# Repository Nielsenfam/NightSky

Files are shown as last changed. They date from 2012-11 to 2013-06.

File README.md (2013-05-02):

Night Sky Orb
=============

By Terry Nielsen
----------------

The Night Sky Orb is a RaspberryPi based "clock" that gives a quick summary
of the objects visible in the night sky for the current night by turning 
on/off an LED representative of each hour in the night.

Status:
-------
Working Prototype

Two versions: 
-------------

1. Tk based GUI: LEDgrid.py
2. i2c version: LEDgridDrive.py

LEDgridDrive.py needs to be run as root and should be run on startup. 

It will drive a LED matrix connected to the i2c port of the raspberry pi. 

See setup instructions, Setup.md for setting up Raspberry Pi from clean install

Notes: 
------

1. LED driver version needs more testing

Objects supported inlcude:
--------------------------

## Earth: ##
Displays an indication of the cloud cover, transparancy, and seeing
on indicates "mostly clear and at least avg transparency and avg seeing"
off indicates "not clear or poor transparancy or poor seeing"

## Sun: ##
Indicates time of sunset/sunrise "on" is sun is out.

## Moon: ##
Indicates when the moon is visible, "on" is moon is out, brightness 
indicates how bright the moon is.

## ISS: ##
Any International Space Station Passes, count the # of flashes 
to tell what the 10 minute period of the hour it is visible.

## Venus: ##
On indicates Venus is visible that hour 

## Mars: ##
On indicates Mars is visible that hour

## Saturn: ##
On indicates Saturn is visible that hour

## Jupiter: ##
On indicates Jupiter is visible that hour

Originally designed for an 8x8 LED matrix to go from hours 7PM to 2AM and 
driven directly by an Arduino with a wifi connection to the code on a 
seperate server.

Redesigned for RaspberryPi, with local code connected to a wifi dongle 
and an LED matrix driven by i2c bus driver.

Enhancement Ideas:
=================

1. The i2c LED matrix could be larger to cover 12 hours for the whole "night". 
Might be easier to use a second Backpack at a different address

2. The Earth Sky conditions could display additional observing conditions 
such as those found on cleardarksky.com.

3. i2c could also drive additional 7 segement display for 
traditional "clock" functionality.

4. Combined with Above, a pushbutton could be used to display exact 
times of Rise/Set on a 7 segment display

5. Another button could also display details of sky conditions

6. Make configurable which night sky objects to show

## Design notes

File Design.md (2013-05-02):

Project: Easy to View Night Sky Summary Display "Clock"
=======================================================

Name: NightSkyOrb
-----------------

Queries server each day to get status of sun rise/set, moon rise/set, planets visible, weather summary, and ISS passes.

Do as a "grid" of 8 x 8 LEDs:

- For each body show visible Time Of Day: 7,8,9,10,11,12,1,2

- Off = not visible, dim = rising/setting, bright = in sky
	
1. Earth (Sky): Earth: Off = Cloudy, Dim = Party Cloudy, Bright = Clear Skys
2. Sun: Sun: On = visible, Off = not visible (or should this reverse?)
3. Moon: Moon: Off = not visible, dim = 0-20 degrees, dim = above 20 degrees but less than half full, bright = above 20 degrees, more than half full
4. ISS: Off = not visible, Visible Pass, flashes 1 time for every 10 minutes past hour
5. Venus: Bright = In Sky, above 10 degrees, Dim = 0-20 degrees, Off = not visible
6. Mars: Bright = In Sky, above 10 degrees, Dim = 0-20 degrees, Off = not visible
7. Jupiter: Bright = In Sky, above 20 degrees, Dim = 0-20 degrees, Off = not visible
8. Saturn: Bright = In Sky, above 20 degrees, Dim = 0-20 degrees, Off = not visible

Message String:
----------------
Originally designed to communicate to Arduino, not really needed now

header: 'X', 
row num=0-9, 
col count=8, 
ascii data string one char per column, footer: 'Z\n',  

info for each LED: 
	
+ a = off
+ b = dim
+ c = on/bright
+ d = slow flash 10 secs on, 10 off	
+ f = slow flash 10 seconds on 10 off
+ g = 1 flash: 1 sec on, 1 off, 10 off (for minutes :00-09:59)
+ h = 2 flash: 1 on, 1 off, 1 on, 1 off, 10 sec off (for minutes :10-19:59)
+ i = 3 flash: 1 on, 1 off, 1 on, 1 off, 1 on, 1 off, 10 off (for minutes :20-29:59)
+ j = 4 flash: 4x 1 on/off, 10 off (for minutes :30-39:59)
+ k = 5 flash: 5x 1 on/off, 10 off (for minutes :40-49:59)
+ l = 6 flash: 6x 1 on/off, 10 off (for minutes :50-59:59)

Example: row 2 is for sun setting in 9PM hour:
		X28ccbaaaaaZ\n
		
Example: row 3 is for near full moon rising at 10PM:
		X38aaabccccZ\n
		
Example: row 4 is for ISS making a visible pass at 10:35PM
		X48aaajaaaaZ\n
		
Example: row 6 is for Mars visible from sunset (9PM) till 11PM, going to 20 degrees from horizon in 10PM hour
		X46aabcbaaaZ\n 	

LED display:
------------

Now using Adafruit LED backpack
 		
Intend to put individual LEDs into a frame similar to:

http://www.flickr.com/photos/spikenzie/3674197080/in/set-72157603968192071/	
 		
from: http://www.spikenzielabs.com/SpikenzieLabs/Main.html
http://www.spikenzielabs.com/SpikenzieLabs/8x8.html	

with LEDS could color code by object:
+ Sun: Yellow
+ Earth: Blue
+ Moon: White
+ ISS: Blue
+ Venus: Yellow
+ Mars: Red
+ Jupiter: Orange
+ Saturn: Yellow
	
A row of LEDS for each object, and then a label on the top or side of the object for hours?
	
Time is on the X axis. 

Use IKEA picture frame

LEDs in http://www.spikenzielabs.com/SpikenzieLabs/8x8.html

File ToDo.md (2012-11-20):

To Do:
======

GUI:
----

+ clean up code
	
+ comment code
	
+ build test stubs

+ better error handling
	
+ parameterize location (both cleardarksky and lat/lon/alt)
+ parameterize start and end times (7PM-2PM currently hardcoded)
+ parameterize colors (for GUI)
+ parameterize objects, other planets, satallites, 

LEDdriver:
----------

+ make work with 2 LED arrays for more hours

Next Steps:
-----------

+ Design Frame
+ Build Frame
+ Mount LEDs
+ Wire LED array
+ Build and Test

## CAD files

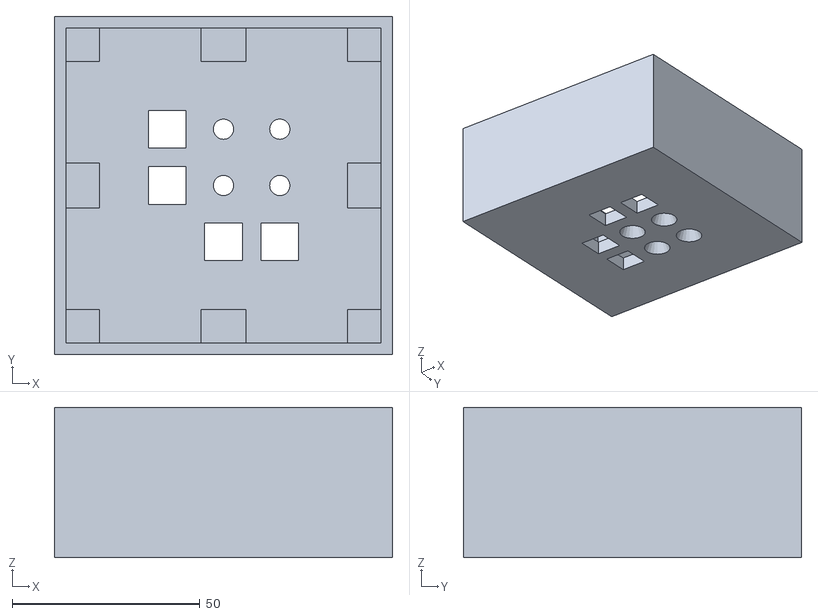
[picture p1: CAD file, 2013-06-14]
case/MainBox-test.stl
90.0 x 90.0 x 40.0

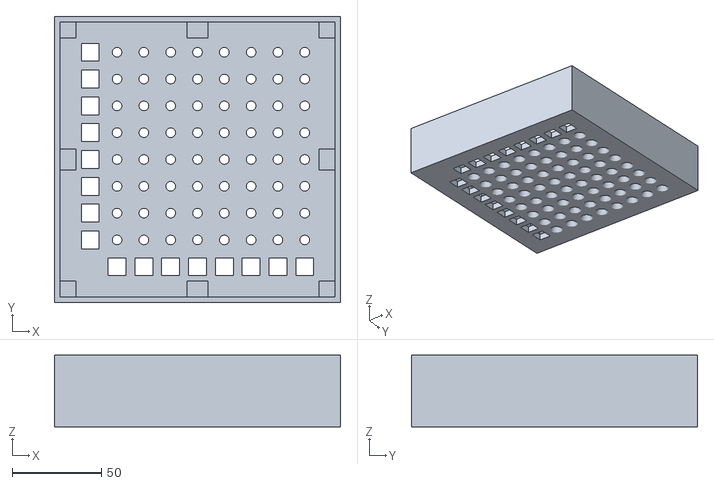
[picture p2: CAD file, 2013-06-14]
case/MainBox.stl
160.0 x 160.0 x 40.0

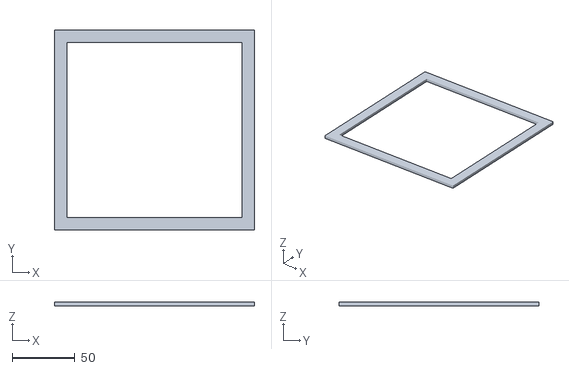
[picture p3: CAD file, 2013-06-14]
case/DecorFrame.stl
160.0 x 160.0 x 3.00

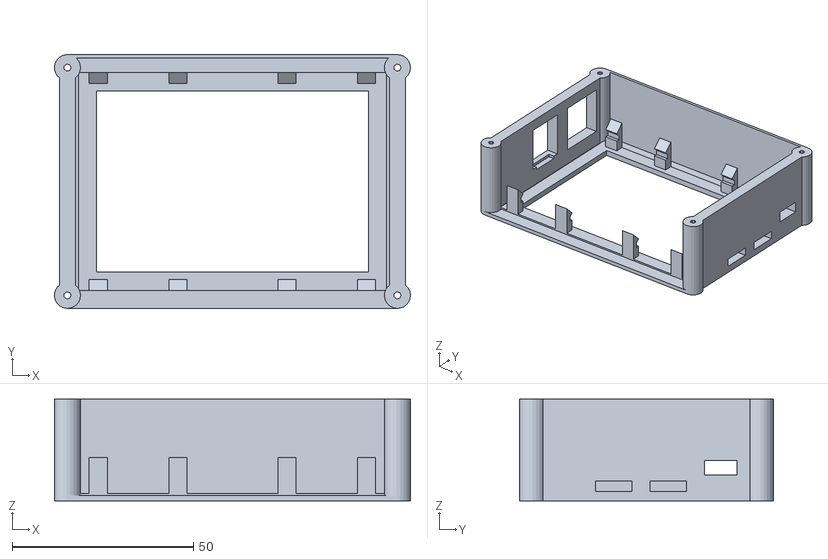
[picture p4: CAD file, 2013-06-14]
case2/base.stl
98.2 x 70.0 x 28.0

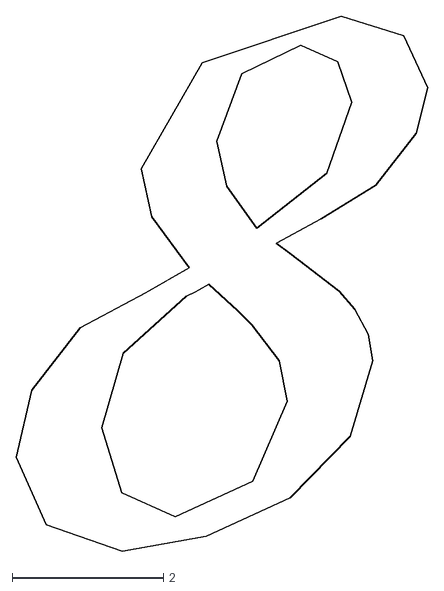
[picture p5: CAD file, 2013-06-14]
case/eight.dxf
5.44 x 7.07

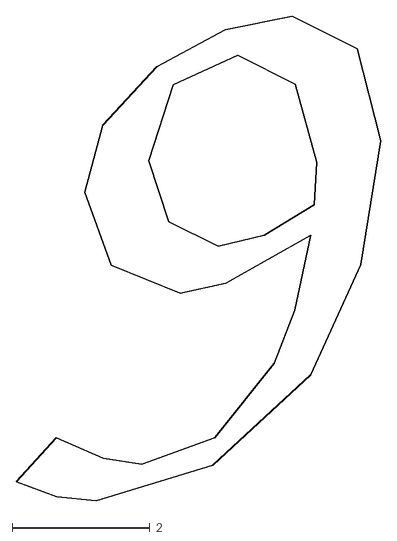
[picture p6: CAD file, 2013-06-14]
case/nine.dxf
5.30 x 7.05

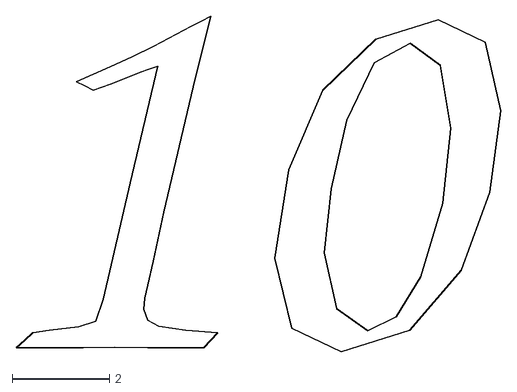
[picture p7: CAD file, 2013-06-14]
case/ten.dxf
9.96 x 6.90

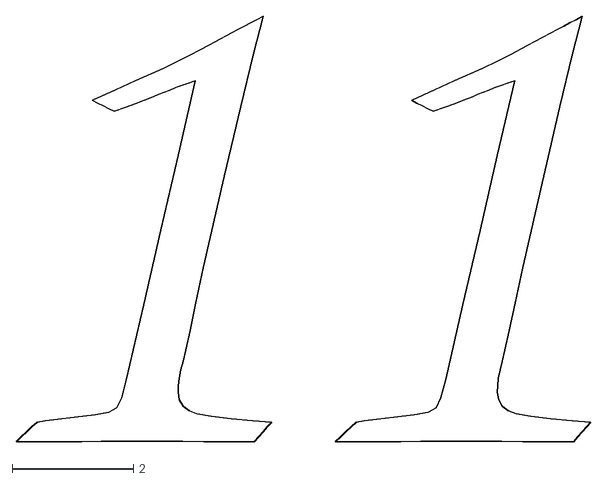
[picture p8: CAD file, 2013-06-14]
case/eleven.dxf
9.49 x 7.02

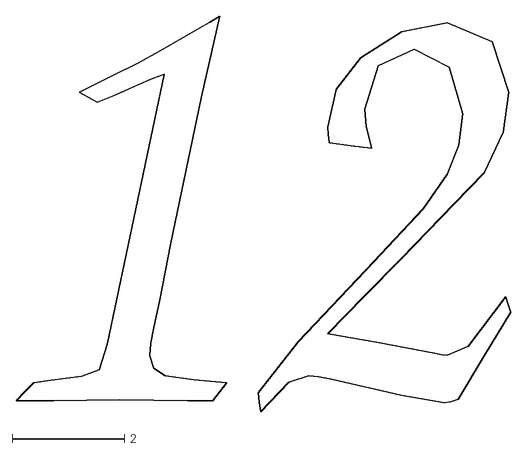
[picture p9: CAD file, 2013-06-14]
case/twelve.dxf
8.83 x 7.06

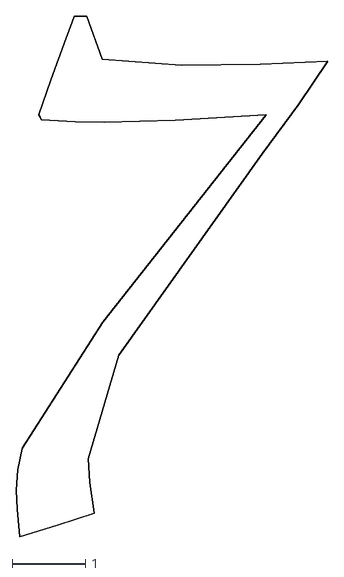
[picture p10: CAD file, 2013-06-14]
case/seven.dxf
4.24 x 7.10

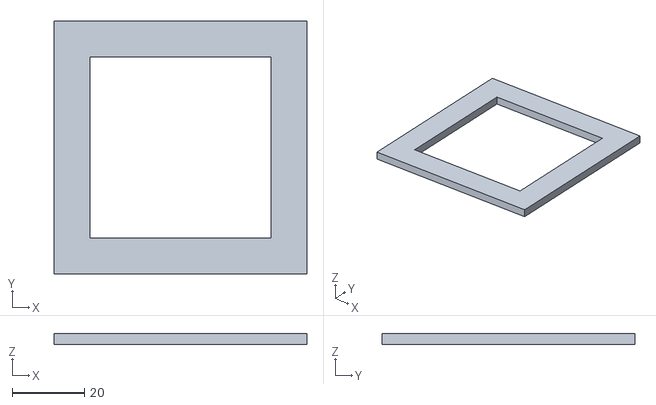
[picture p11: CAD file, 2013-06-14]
case/DecorFrame-test.stl
70.0 x 70.0 x 3.00

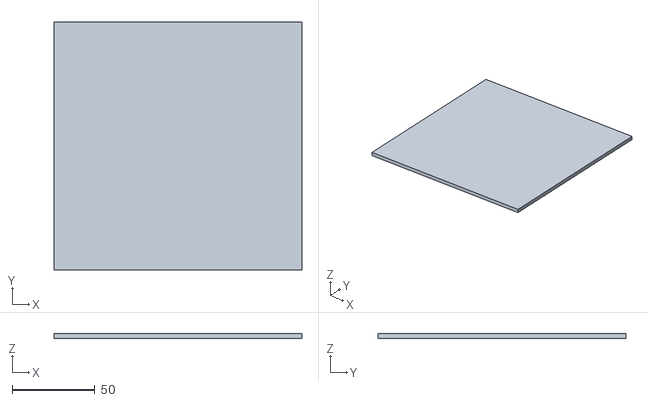
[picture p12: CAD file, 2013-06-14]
case/BackPanel.stl
149.5 x 149.5 x 3.00

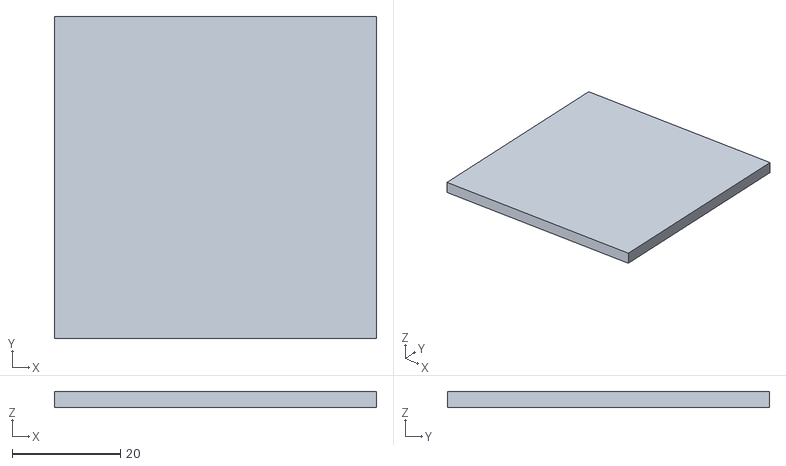
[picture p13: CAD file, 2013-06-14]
case/BackPanel-test.stl
59.5 x 59.5 x 3.00

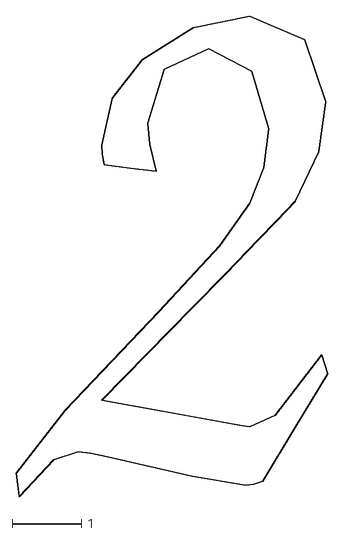
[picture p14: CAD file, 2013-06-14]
case/two.dxf
4.51 x 6.95

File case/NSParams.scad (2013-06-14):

//
// box for Night Sky Orb LED clock
//   designed by: Terry Nielsen
//
//   Parameter File
//

//
// box parameters
//

// Square box of this size in mm

// test: box_width = 90;
box_width = 160;

// box is this deep in mm

box_depth = 40;

// box has walls this thick in mm
wall_thickness=3;

// box has corner braces this size in mm
corner_size = 12;

// make lip on decorative frame of front of panel
lip_width = 10;
lip_thickness = 3;

// front panel is this thick in mm
panel_thickness=5;

// back panel is this thick in mm
back_panel_thickness = 3;

// corner braces are recessed from the back
corner_recess=back_panel_thickness + 2;

// size of object holes
object_hole_size = 10;

// seperation between object holes and grid holes
object_grid_seperation = 5;


//
// LED parameters
//

// number of LEDs in row:

// test: led_row_count = 2;
led_row_count = 8;
led_col_count = led_row_count; // make it a square grid

// LED hole resolution

led_resolution = 20;

// LED holes have this diamter in mm
led_hole_back_dia=5;

// make this bigger to make hole wider at front of panel
led_hole_front_dia=led_hole_back_dia*2;

// LED holes are spaced this far apart in the grid in mm
led_hole_spacing=15;

// LED grid hole pattern is offset from the sides this far:
led_hole_pattern_offset = 
    ( ( box_width
        - ( led_hole_spacing*(led_row_count-1) ) ) / 2 )
    + ( ( object_hole_size + object_grid_seperation ) / 2 );

//
// End of parameters
//

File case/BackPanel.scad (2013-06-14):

//
// box for Night Sky Orb LED clock
//   designed by: Terry Nielsen
//

include <NSParams.scad>

//
// draw back panel
//

cube(size=[(box_width-wall_thickness*2)-0.5,
           (box_width-wall_thickness*2)-0.5,
           back_panel_thickness]);

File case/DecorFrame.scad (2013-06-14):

//
// box for Night Sky Orb LED clock
//   designed by: Terry Nielsen
//

include <NSParams.scad>

// A simple decorative frame to go on front panel

// draw box lip
difference() {
   cube(size=[box_width,box_width,lip_thickness]);
   translate([lip_width,lip_width,0])
      cube(size=[box_width-lip_width*2,
                 box_width-lip_width*2,
                 lip_thickness]);
}

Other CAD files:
case/one.dxf
case/MainBox.scad
case2/base.scad
case2/ledmatrix.scad
case2/pibase.scad

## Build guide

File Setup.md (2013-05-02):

Instructions to setup a Raspberry Pi to run the NightSkyOrb
===========================================================

Set up new SD card with raspbian distribution
---------------------------------------------

Insert SD card and do config:
     Expand to full card, reset password, set timezone

setup wifi
----------

Using gui tool on desktop

setup keyboard
--------------

    # sudo vi /etc/default/keyboard and change "gb" to "us"

reboot after that

    # sudo reboot

get current updates
-------------------

In terminal window do this to get to most current packages:

    # sudo apt-get update
    # sudo apt-get upgrade

setup python development environment
------------------------------------

In terminal window get python development environment and python install package tool

    # sudo apt-get install python-pip python-dev

setup necessary python packages for astronomical calculations
-------------------------------------------------------------

get stuff for calculating ephem by getting pyephem and putz packages:

    # sudo pip install pyephem pytz

setup git so we can retrieve code
---------------------------------

get git so we can get NightSky code:

    # sudo apt-get install git

retrieve code from github:

    # git clone http://github.com/Nielsenfam/NightSky

Setup for GPIO and i2c access from python
-----------------------------------------

    # sudo apt-get install python-rpi.gpio
    # sudo apt-get install python-smbus i2c-tools

Now enable gpio and smbus access from kernel:

    # sudo vi /etc/modules

in editor add these two lines to end of file:

    i2c-bcm2708 
    i2c-dev

And also need to remove from blacklist

    # sudo vi /etc/modprobe.d/raspi-blacklist.conf

in vi comment out two lines:

    blacklist spi-bcm2708
    blacklist i2c-bcm2708

And finally need to reboot to get kernel updated

    # reboot

Configuring and Validation
--------------------------

Edit params.py to match location:

    # vi params.py

Change latitude, longitude, and cleardarksky location

To validate it all works:

    # sudo python LEDgrid.py

if all is working should see desktop graphical "LED" version of the NightSkyOrb

Now test the LED matrix grid version: 

RiPi needs to have LED 8x8 grid backpack connected to GPIO, see instructions from Adafruit

    # sudo i2cdetect -y 0

Change to 1 if on 512Mb

should see 70 if backpack is connected

Now test LED grid by typing this:

    # sudo test_LEDmatrix.py

LED matrix should scan all elements

Now run the LEDgridDrive.py version:

    # sudo python LEDgridDrive.py

If it all works, the LEDs should look same as the desktop graphical LED orb

Setup Desktop Icon
------------------

    # cp nightsky.desktop ~/Desktop

Setup to autostart
------------------

    # sudo vi /etc/rc.local

add this to file right before the Print My IP address comment

    /home/pi/NightSky/nightsky.sh start

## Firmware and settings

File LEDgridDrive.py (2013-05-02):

#!/usr/bin/python

import os
import time
import datetime

from Adafruit_8x8 import EightByEight

import NSEphem

try:
   grid = EightByEight(address=0x70)
except IOError:
   print "LED Grid not connected, exiting"
   exit()

def flash(r,c,cnt,t):
   if ( cnt*2 > t ):
      if (t % 2 == 0 ):
        grid.setPixel(r,7-c,1)
      else:
        grid.setPixel(r,7-c,0)
   else:
      grid.setPixel(r,7-c,0)

ticks = 0
day_done = -1

while (True): 

   # refresh strings every day at 8AM
   now = datetime.datetime.now()
   if ( day_done != now.day ):
      # print "day, hour, minute", now.day, now.hour, now.minute

      if ((now.hour == 8 and now.minute < 5) or (day_done == -1)):
         # print "getting new strings"
         All_NS_obj = NSEphem.CreateAllNightSkyStrings()
         all_NS_strings = All_NS_obj.get_all_NS_strings()
         day_done = now.day

   ticks = ticks +1
   if (ticks > 20): 
      ticks = 0
            
   for row, aNightSkyString in enumerate(all_NS_strings):      
           
      NS_object_string = aNightSkyString
            
      # test strings:

      #   Earth
      #if (row == 1):
      #   NS_object_string = "X18ccccccccZ"

      #   Sun
      #if (row == 2):
      #   NS_object_string = "X28ccaaaaaaZ"

      #   Moon
      #if (row == 3):
      #   NS_object_string = "X38cbaaaaaaZ"

      #   ISS
      #if (row == 4):
      #   NS_object_string = "X48aaajakaaa"

      #   Venus
      #if (row == 5):
      #   NS_object_string = "X58cccaaaaaZ"

      #   Mars
      #if (row == 6):
      #   NS_object_string = "X68abccccccZ"

      #   Jupiter
      #if (row == 7):
      #   NS_object_string = "X78aaaaaaabc"

      #   Saturn
      #if (row == 8):
      #   NS_object_string = "X88ccbaaaaaa"

      #print "row, string", row, NS_object_string
            
      for col in range (0,8):
         char = NS_object_string[col+3]
         if (char=='a'):
             grid.setPixel(row,7-col,0)
         if (char=='b'):
             grid.setPixel(row,7-col,1)
         if (char=='c'):
             grid.setPixel(row,7-col,1)
         if (char=='g'):
             flash(row,col,1,ticks)
         if (char=='h'):
             flash(row,col,2,ticks)
         if (char=='i'):
             flash(row,col,3,ticks)
         if (char=='j'):
             flash(row,col,4,ticks)
         if (char=='k'):
             flash(row,col,5,ticks)
         if (char=='l'):
             flash(row,col,6,ticks)

   time.sleep(0.1)

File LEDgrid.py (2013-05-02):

#!/usr/bin/python

import os
import sys


from Tkinter import *
from functools import partial

import NSEphem

class LEDGrid:
    
    def __init__(self, top):

        file = sys.argv[0]
        __dir__ = os.path.dirname(file)
        # __dir__ = os.path.dirname(os.path.abspath(__file__))
        self.LED_red_on_photo = PhotoImage(file=os.path.join(__dir__,'LED-red-on.gif'))
        self.LED_yellow_on_photo = PhotoImage(file=os.path.join(__dir__,'LED-yellow-on.gif'))
        self.LED_blue_on_photo = PhotoImage(file=os.path.join(__dir__,'LED-blue-on.gif'))
        self.LED_orange_on_photo = PhotoImage(file=os.path.join(__dir__,'LED-orange-on.gif'))
        self.LED_white_on_photo = PhotoImage(file=os.path.join(__dir__,'LED-white-on.gif'))
        self.LED_red_dim_photo = PhotoImage(file=os.path.join(__dir__,'LED-red-dim.gif'))
        self.LED_yellow_dim_photo = PhotoImage(file=os.path.join(__dir__,'LED-yellow-dim.gif'))
        self.LED_blue_dim_photo = PhotoImage(file=os.path.join(__dir__,'LED-blue-dim.gif'))
        self.LED_orange_dim_photo = PhotoImage(file=os.path.join(__dir__,'LED-orange-dim.gif'))
        self.LED_white_dim_photo = PhotoImage(file=os.path.join(__dir__,'LED-white-dim.gif'))
        self.LED_off_photo = PhotoImage(file=os.path.join(__dir__,'LED-off.gif'))
        self.Earth_photo = PhotoImage(file=os.path.join(__dir__,'earth.gif'))
        self.Sun_photo = PhotoImage(file=os.path.join(__dir__,'sun.gif'))
        self.Moon_photo = PhotoImage(file=os.path.join(__dir__,'moon.gif'))
        self.ISS_photo = PhotoImage(file=os.path.join(__dir__,'ISS.gif'))
        self.Venus_photo = PhotoImage(file=os.path.join(__dir__,'venus.gif'))
        self.Mars_photo = PhotoImage(file=os.path.join(__dir__,'mars.gif'))
        self.Jupiter_photo = PhotoImage(file=os.path.join(__dir__,'jupiter.gif'))
        self.Saturn_photo = PhotoImage(file=os.path.join(__dir__,'saturn.gif'))
        self.Seven_photo = PhotoImage(file=os.path.join(__dir__,'Seven.gif'))
        self.Eight_photo = PhotoImage(file=os.path.join(__dir__,'Eight.gif'))
        self.Nine_photo = PhotoImage(file=os.path.join(__dir__,'Nine.gif'))
        self.Ten_photo = PhotoImage(file=os.path.join(__dir__,'Ten.gif'))
        self.Eleven_photo = PhotoImage(file=os.path.join(__dir__,'Eleven.gif'))
        self.Twelve_photo = PhotoImage(file=os.path.join(__dir__,'Twelve.gif'))
        self.One_photo = PhotoImage(file=os.path.join(__dir__,'One.gif'))
        self.Two_photo = PhotoImage(file=os.path.join(__dir__,'Two.gif'))
        self.H_Wood_photo = PhotoImage(file=os.path.join(__dir__,'H-Wood.gif'))
        self.V_Wood_photo = PhotoImage(file=os.path.join(__dir__,'V-Wood.gif'))
        self.bg_color = "#D2691E"
        self.border_color = "#000000"
        self.ticks = 0
        
        self.top = top
        self.button_dic = {}     ## pointer to buttons and StringVar()
        self.button_state_dic = {"on":[], "off":[], "dim":[], "flash1":[], "flash2":[], "flash3":[], "flash4":[], "flash5":[], "flash6":[]}

        self.top.title('Night Sky Orb')
        self.top_frame = Frame(self.top, width =700, height=700, bg=self.bg_color)
        self.buttons()
        self.top_frame.grid(row=0, column=1)
        
        self.create_left_labels()
        
        self.All_NS_obj = NSEphem.CreateAllNightSkyStrings()

        #exit = Button(self.top_frame, text='Exit', \
        #     command=self.top.quit).grid(row=10,column=0, columnspan=5)
        
        #update = Button(self.top_frame, text='Update', \
        #     command=self.update_cb_handler).grid(row=10,column=2, columnspan=5)

        all_NS_strings = self.All_NS_obj.get_all_NS_strings()

        for i, aNightSkyString in enumerate(all_NS_strings):      
            
            NS_object_string = aNightSkyString
            row = i + 1
            
            # test code for flashing test
            #if row == 4:
            #    NS_object_string = "X48lgahaijkZ"
            
            
            #print "row, string", row, NS_object_string
            #print NS_object_string
            

            
            self.update_LED_row(row, NS_object_string)
                            
        #print "creating bottom labels"    
        self.create_bottom_labels(10)
        
        self.blink()        
        
    def create_left_labels(self):
        for j in range(0,11):
            ColLbl = Label(self.top_frame,image=self.V_Wood_photo,height=54,width=54,relief="flat",fg=self.border_color,bd=0)
            ColLbl.grid(row=j, column=0)
                  
    def create_top_labels(self):
        for j in range(1,10):
            ColLbl = Label(self.top_frame,image=self.H_Wood_photo,height=54,width=66,relief="flat",bd=0)
            ColLbl.grid(row=0, column=j)
        ColLbl = Label(self.top_frame, bg=self.bg_color)
        ColLbl.grid(row=1, column=1)
        ColLbl = Label(self.top_frame, image=self.Seven_photo, bg=self.bg_color,height=50,width=50)
        ColLbl.grid(row=1, column=2)
        ColLbl = Label(self.top_frame, image=self.Eight_photo, bg=self.bg_color,height=50,width=50)
        ColLbl.grid(row=1, column=3)
        ColLbl = Label(self.top_frame, image=self.Nine_photo, bg=self.bg_color,height=50,width=50)
        ColLbl.grid(row=1, column=4)
        ColLbl = Label(self.top_frame, image=self.Ten_photo, bg=self.bg_color,height=50,width=50)
        ColLbl.grid(row=1, column=5)
        ColLbl = Label(self.top_frame, image=self.Eleven_photo, bg=self.bg_color,height=50,width=50)
        ColLbl.grid(row=1, column=6)
        ColLbl = Label(self.top_frame, image=self.Twelve_photo, bg=self.bg_color,height=50,width=50)
        ColLbl.grid(row=1, column=7)
        ColLbl = Label(self.top_frame, image=self.One_photo, bg=self.bg_color,height=50,width=50)
        ColLbl.grid(row=1, column=8)
        ColLbl = Label(self.top_frame, image=self.Two_photo, bg=self.bg_color,height=50,width=50)
        ColLbl.grid(row=1, column=9)
        
    def create_bottom_labels(self,row_num):
        for j in range(1,10):
            ColLbl = Label(self.top_frame,image=self.H_Wood_photo,height=54,width=66,relief="flat",fg=self.border_color,bd=0)
            ColLbl.grid(row=row_num, column=j)

    def button_flasher(self, square_number, flash_count ):
            if self.ticks == 0:
                self.button_dic[square_number][1].config(image=self.LED_blue_on_photo)        
            if self.ticks == 1:
                self.button_dic[square_number][1].config(image=self.LED_off_photo)
            if self.ticks == 2:
                self.button_dic[square_number][1].config(image=self.LED_blue_on_photo)
                
            if self.ticks == 3 and flash_count > 1:
                self.button_dic[square_number][1].config(image=self.LED_off_photo)
            if self.ticks == 4 and flash_count > 1:
                self.button_dic[square_number][1].config(image=self.LED_blue_on_photo)
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

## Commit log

2012-11-15 Added LED Matrix driver code
2012-11-15 Updated to reflect addition of LED matrix drivers
2012-11-20 Changed to LED on for good skys
2012-11-20 Fixed Earth after midnight
    [CreateEarthString.py]
2012-11-21 Fixed some bugs in working copy of NSEphem
    [NSEphem.py]
2012-11-30 Fixed Adafruit I2C code so that it raises IOError if not connected Added logic in LEDgridDrive to detect IOError and exit
    [Adafruit_I2C.py, Adafruit_LEDBackpack.py, LEDgridDrive.py]
2013-05-01 Updated LEDgrid to use Ephem version
2013-05-06 Added case design files
    [BackPanel-test.stl, BackPanel.scad, BackPanel.stl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]
2013-05-07 Added square holes for object pictures and hour numbers
    [MainBox.scad, MainBox.stl, NSParams.scad]
2013-05-07 Regenerated Test Box with object holes
    [MainBox-test.stl, NSParams.scad]
2013-05-07 Added svg and dxf files for clock numbers
    [eight.dxf, eleven.dxf, nine.dxf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]
2013-05-07 Updated to use dxf files for numbers.
    [MainBox.scad]
2013-05-14 Added case design #2.
    [base.scad, base.stl, ledmatrix.scad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]
2013-05-16 Changed pilot holes. Still need to parameterize a few things.
    [base.scad, ledmatrix.scad]
2013-05-16 Updated STL files.
    [base.stl]
2013-06-14 Fixed bug in sky condition comparision against parameters
    [CreateEarthString.py]
